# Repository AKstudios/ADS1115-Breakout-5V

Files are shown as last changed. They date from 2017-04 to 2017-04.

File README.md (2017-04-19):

# ADS1115 Breakout 5V
This is a modified version of the ADS1115 breakout board by Adafruit. It takes analog inputs between 0-5V, but the I2C interface is at 3.3V with the addition of logic level shifting circuitry to interface with 3.3V MCUs. All passive components are 0402 parts to fit everything on the board.

The board takes in raw power (2-16V) through the PWR pin and supplies a steady 5V to all components (MCP1703 LDO Vreg). The board has an input header for 3.3V supply for the level shifting circuit.

ALRT pin is not broken out, but still pulled up to 5V on the board.

<p align="center">
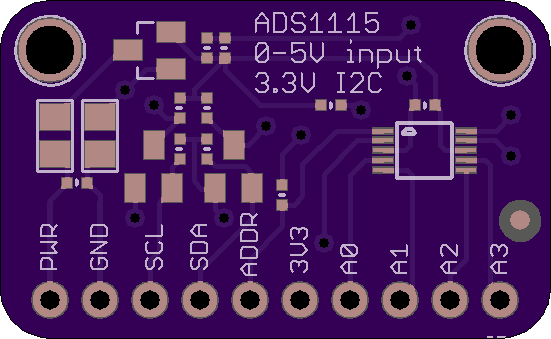
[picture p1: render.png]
CRT Sensor Board
  
</p>

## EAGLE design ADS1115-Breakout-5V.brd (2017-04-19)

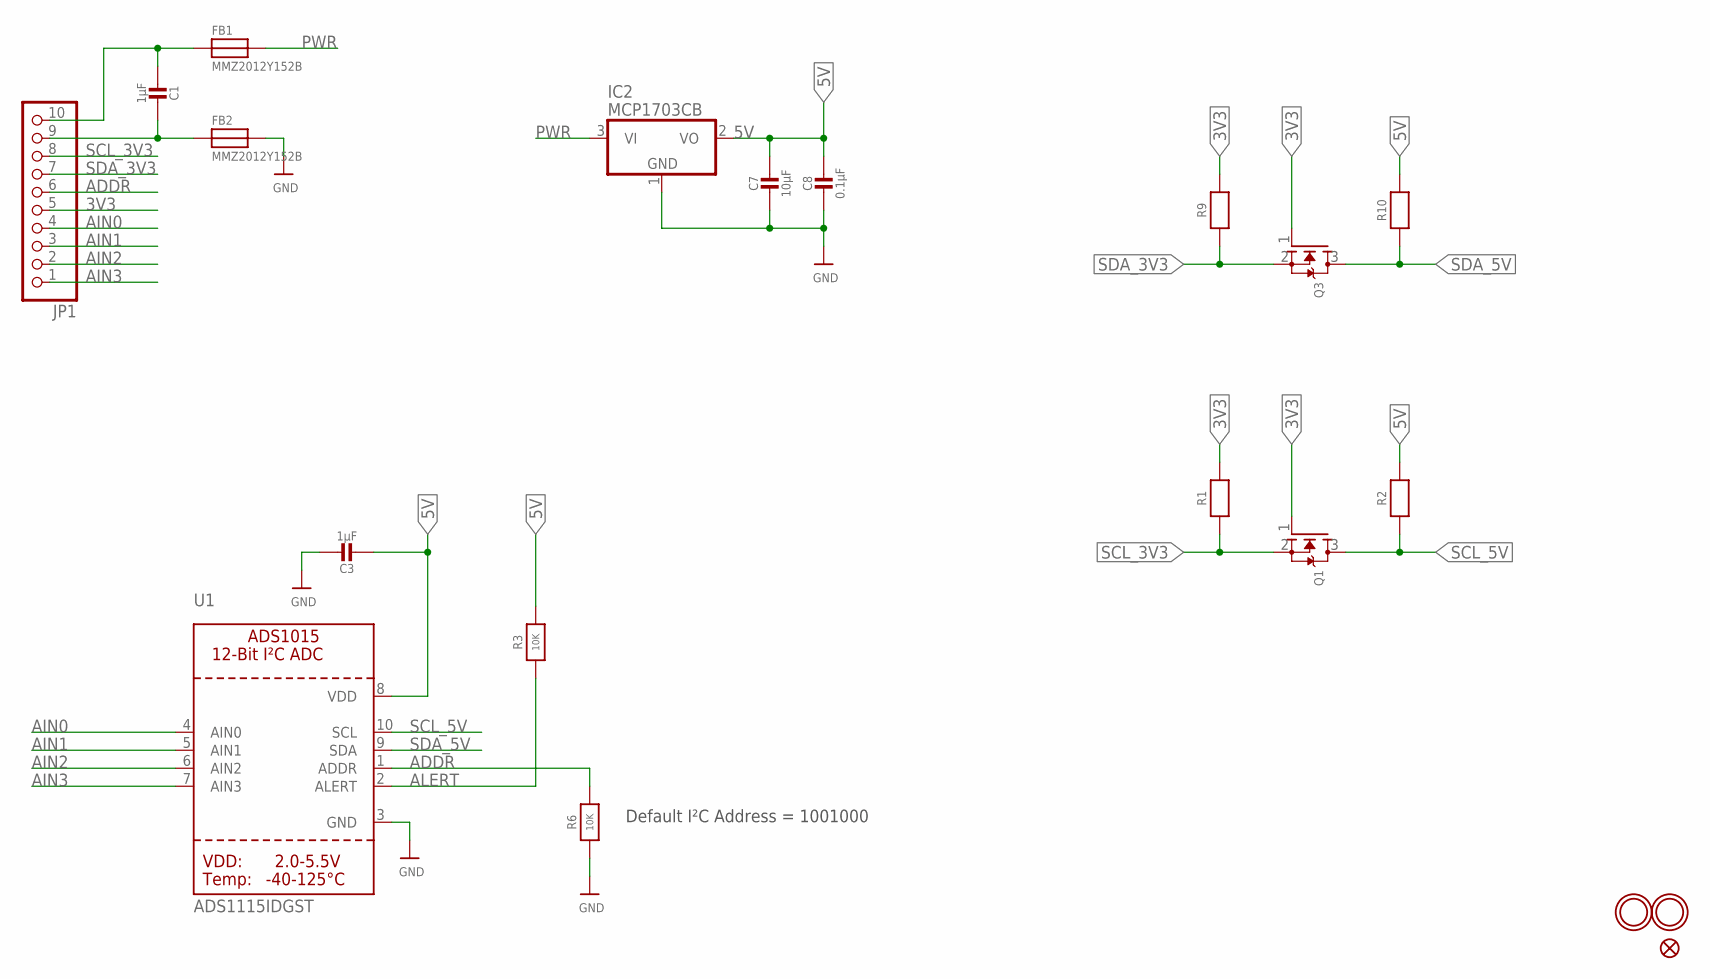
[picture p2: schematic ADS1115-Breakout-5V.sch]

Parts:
C1, C3: 1µF; _0402MP
C7: 10µF; _0402MP
C8: 0.1µF; _0402MP
FB1, FB2: MMZ2012Y152B; 0805
FID1: FIDUCIAL""; FIDUCIAL_1MM
IC2: MCP1703CB; SOT23
JP1: HEADER-1X1070MIL; 1X10_ROUND70
Q1, Q3: MOSFET-NREFLOW; SOT23
R1, R2, R9, R10: RESISTOR_0402MP; _0402MP
R3, R6: 10K; _0402MP
U1: ADS1115IDGST; MSOP10
U$13, U$14: MOUNTINGHOLE2.5; MOUNTINGHOLE_2.5_PLATED

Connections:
3V3: JP1.5, Q1.1 (G), Q3.1 (G), R1.2, R9.2
5V: C3.2, C7.1, C8.1, IC2.2 (VO), R2.2, R3.2, R10.2, U1.8 (VDD)
ADDR: JP1.6, R6.2, U1.1 (ADDR)
AIN0: JP1.4, U1.4 (AIN0)
AIN1: JP1.3, U1.5 (AIN1)
AIN2: JP1.2, U1.6 (AIN2)
AIN3: JP1.1, U1.7 (AIN3)
ALERT: R3.1, U1.2 (ALERT)
GND: C3.1, C7.2, C8.2, FB2.2, IC2.1 (GND), R6.1, U1.3 (GND)
unnamed: C1.2, FB1.1, JP1.10
unnamed: C1.1, FB2.1, JP1.9
PWR: FB1.2, IC2.3 (VI)
SCL_3V3: JP1.8, Q1.2 (S), R1.1
SCL_5V: Q1.3 (D), R2.1, U1.10 (SCL)
SDA_3V3: JP1.7, Q3.2 (S), R9.1
SDA_5V: Q3.3 (D), R10.1, U1.9 (SDA)

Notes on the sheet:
Default I²C Address = 1001000

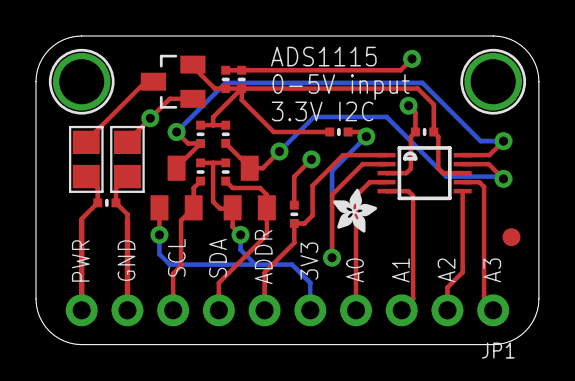
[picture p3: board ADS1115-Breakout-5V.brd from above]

Board: 2 copper layers, 27.9 x 17.1 mm, 22 parts (1 on the bottom side), 16 nets.

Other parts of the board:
U$15: ADAFRUIT_TEXT_20MM
U$16: ADAFRUIT_2.5MM

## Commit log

2017-04-19 Added EAGLE files
    [ADS1115-Breakout-5V.brd, ADS1115-Breakout-5V.sch]
2017-04-19 Some trace & silkscreen adjustments
    [ADS1115-Breakout-5V.brd]
